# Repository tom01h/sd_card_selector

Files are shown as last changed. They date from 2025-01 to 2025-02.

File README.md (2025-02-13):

# ラズパイ5のマイクロSDカードをリモートで書き換えたり、リモートで電源ONにできるやつ

## できること
- マイクロSDカードの接続をラズパイとUSBカードリーダーで切り替えられる
    - 接続の切り替え部分は[これ](https://x.com/task_jp/status/1864548270422573205)の真似
- 電源ボタンを押したのと同じことができる
    - [この資料](https://www.raspberrypi.com/documentation/computers/raspberry-pi.html#add-your-own-power-button)の通りに制御する
- 電源の状態を知れる
    - マイクロSDに供給されている電源を監視
- PCとUSB-UART的なもの（正確にはUSB CDC ACM）で繋ぐ
    - CH552マイコンを使って制御している

## 使い方
こんな感じに組み立てます  
USB-UARTもあったほうが便利です  
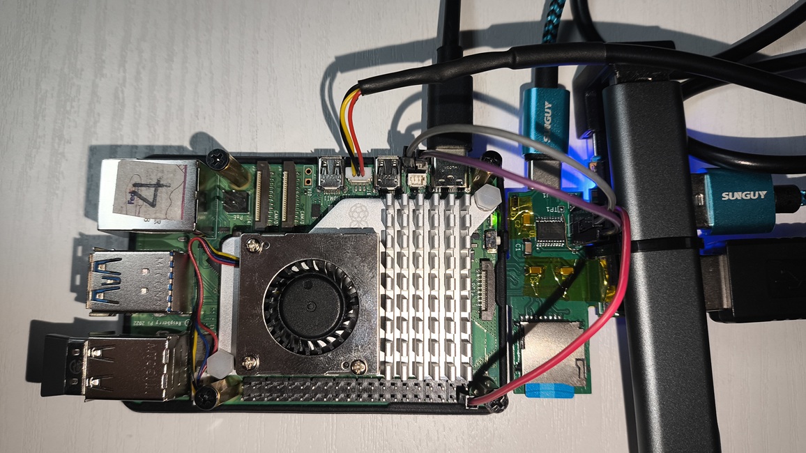
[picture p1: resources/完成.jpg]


ラズパイの電源を入れる前にUSBハブをPCに繋ぎます  
ターミナルの表示は以下  
この状態ではPCからuSDカードにアクセスできます  
```
Raspberry Pi Remote
USB Card Reader
USB> 
```

`rpi`を入力してuSDの接続をラズパイに切り替えます  
この状態ではPCからuSDカードにアクセスできません  
```
USB> rpi
Raspberry Pi
Pi Off>
```

ラスパイの電源を入れて、ターミナルでエンターを入力すると下のような表示になります  
```
Pi Off>
Undefined Command
Pi On>
```

ラスパイをシャットダウンして、ターミナルでエンターを入力すると下のような表示になります  
```
Pi On>
Undefined Command
Pi Off>
```

`pon`を入力してラズパイの電源をONにします  
ターミナルでエンターを入力すると下のような表示になります  
```
Pi Off> pon
Power ON
Pi Off>
Undefined Command
Pi On>
```

`Pi Off`の状態から`usb`コマンドを入力すると、PCからuSDカードにアクセス出来るようになります  
```
Pi Off> usb
USB Card Reader
USB>
```

`Pi On`状態で`shutdown`コマンド実行で、強制的にラズパイの電源をOFFにできます（OSのシャットダウンではありません）  
その後、PCからuSDカードにアクセス出来るようになります  

## 部品
- [USBハブ](https://ja.aliexpress.com/item/1005007046850790.html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)
- [USBカードリーダー](https://ja.aliexpress.com/item/1005007634731826.html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)
- [USBエクステンションアダプター](https://ja.aliexpress.com/item/1005007404846946.html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)
    - コの字型でUSB3.0のやつ
- 自作の基板
    - 設計データはKiCadディレクトリ以下
    - 基板の厚さは0.8mm

### 基板に乗せる部品
- [CH552](https://ja.aliexpress.com/item/1005004508033849.html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)
    - CH552T
- [tmux1574pwr](https://ja.aliexpress.com/item/1005007848132137.html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)
- [1N5819 SOD-123](https://ja.aliexpress.com/item/1005003194674618.html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)
- [XC6206P332MR](https://ja.aliexpress.com/item/1005002918096822.html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)
- [ボタン](https://ja.aliexpress.com/item/32756768334.html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)
    - 買ったやつはリンクなくなった・多分これと同じ
- 抵抗とか容量は1206サイズ（3.2mmx1.6mm）

## 基板の繋ぎ方
### 作成した基板の実装
こんな感じ  
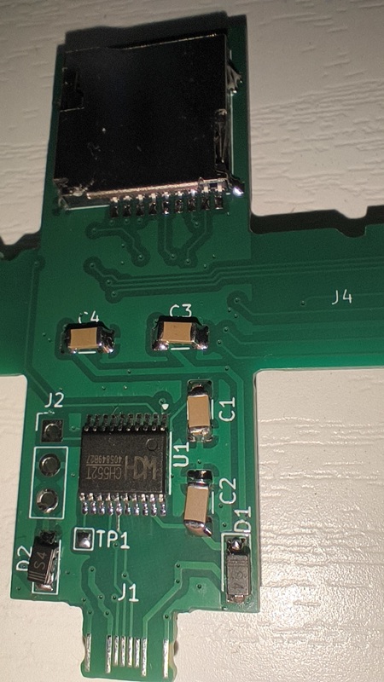
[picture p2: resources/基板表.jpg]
  
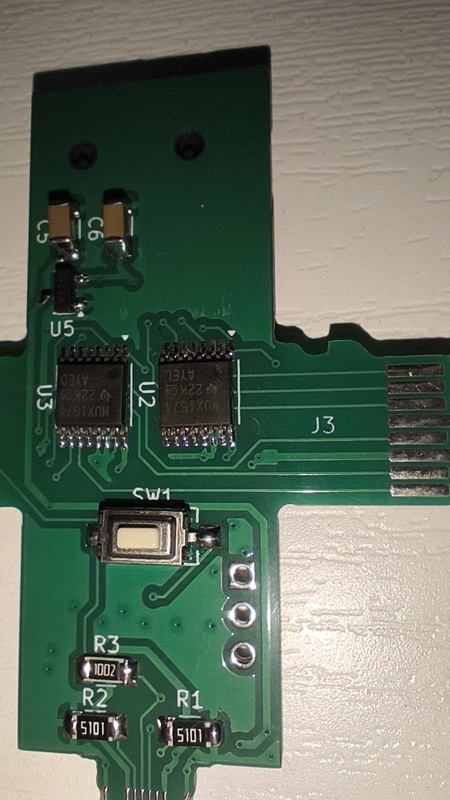
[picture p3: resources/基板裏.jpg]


uSDカードスロットのフットプリントはギリギリ使えるくらいにずれています

### SDカードリーダーの改造
カードリーダーの基板を取り出します  
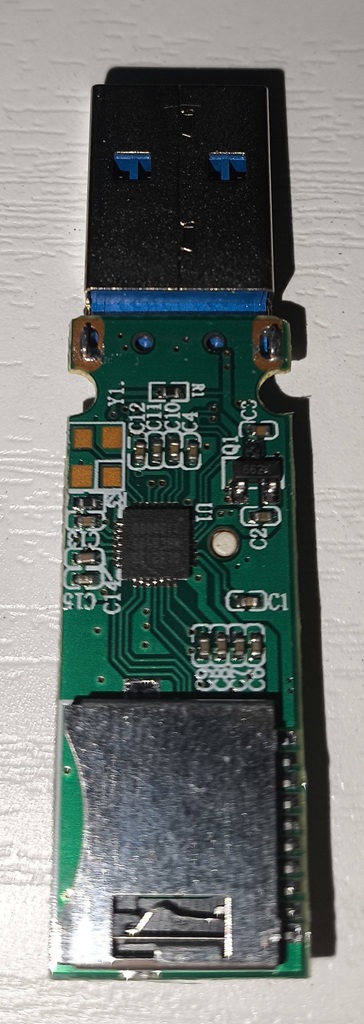
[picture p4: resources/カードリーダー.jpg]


uSDスロットのカードデテクトを壊します  
カードを入れてもdetectピンがグランドに落ちないようにします  
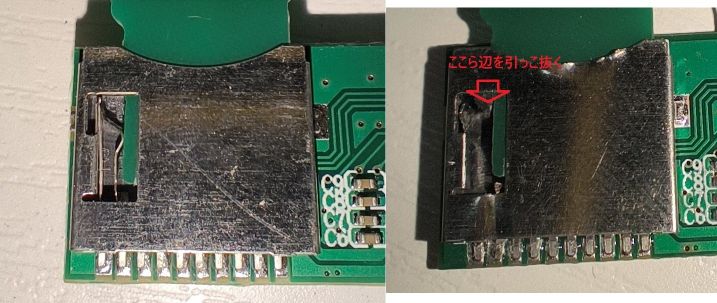
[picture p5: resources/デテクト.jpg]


カードリーダーのSDスロットを外します  
外したソケットのパターンのデテクトピンと作成した基板のTP1を繋ぎます  
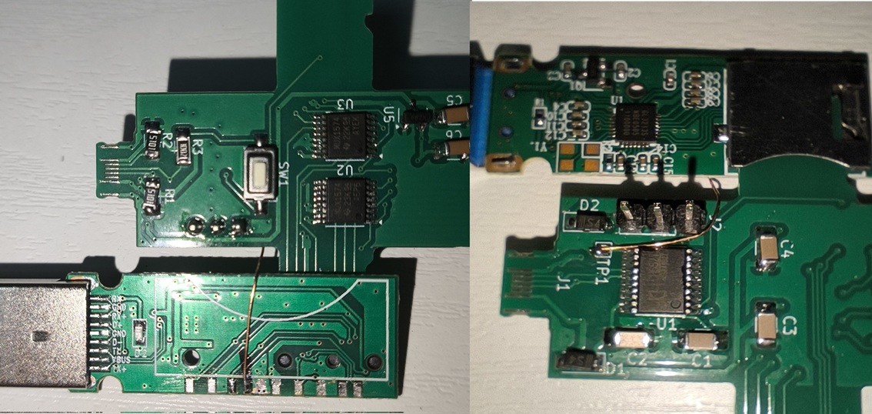
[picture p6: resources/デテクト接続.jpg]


### USBハブの接続
コの字型のアダプタも使ってこんな感じにつなぐ  
5㎜厚の両面テープを3段重ねで止めています  
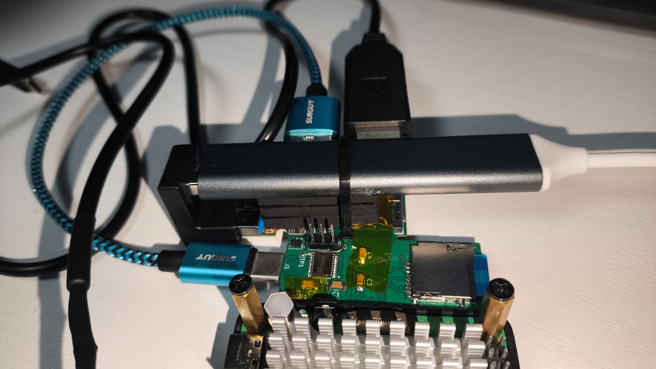
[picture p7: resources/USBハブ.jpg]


### ピンヘッダ(J2)の接続
- 1PINはPSWピンヘッダの1PIN
- 2PINはPSWピンヘッダの2PIN (GND)
- 3PINはラズパイピンヘッダの5V出力
    - 電源はUSBからもとっているので、この接続がなくても動きます

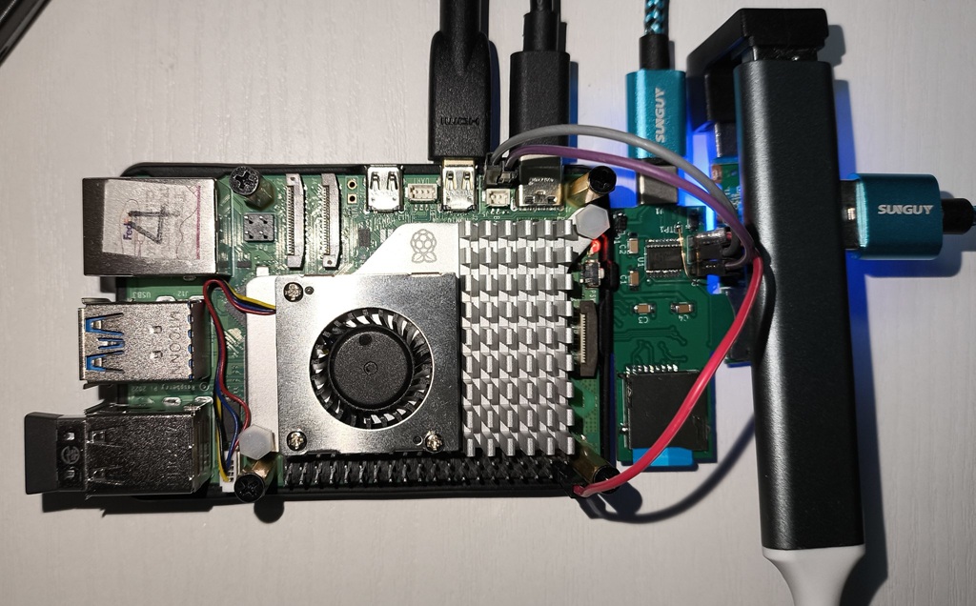
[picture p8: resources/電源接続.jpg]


## CH552のソフト
[ch55xduino](https://github.com/DeqingSun/ch55xduino)を使って、CH552にArduino IDEからプログラム(Arduino/SDSEL/SDSEL.ino)を書きみます  
プログラムの書き込みには[WCHISPTool](https://www.wch.cn/downloads/WCHISPTool_Setup_exe.html)が必要です

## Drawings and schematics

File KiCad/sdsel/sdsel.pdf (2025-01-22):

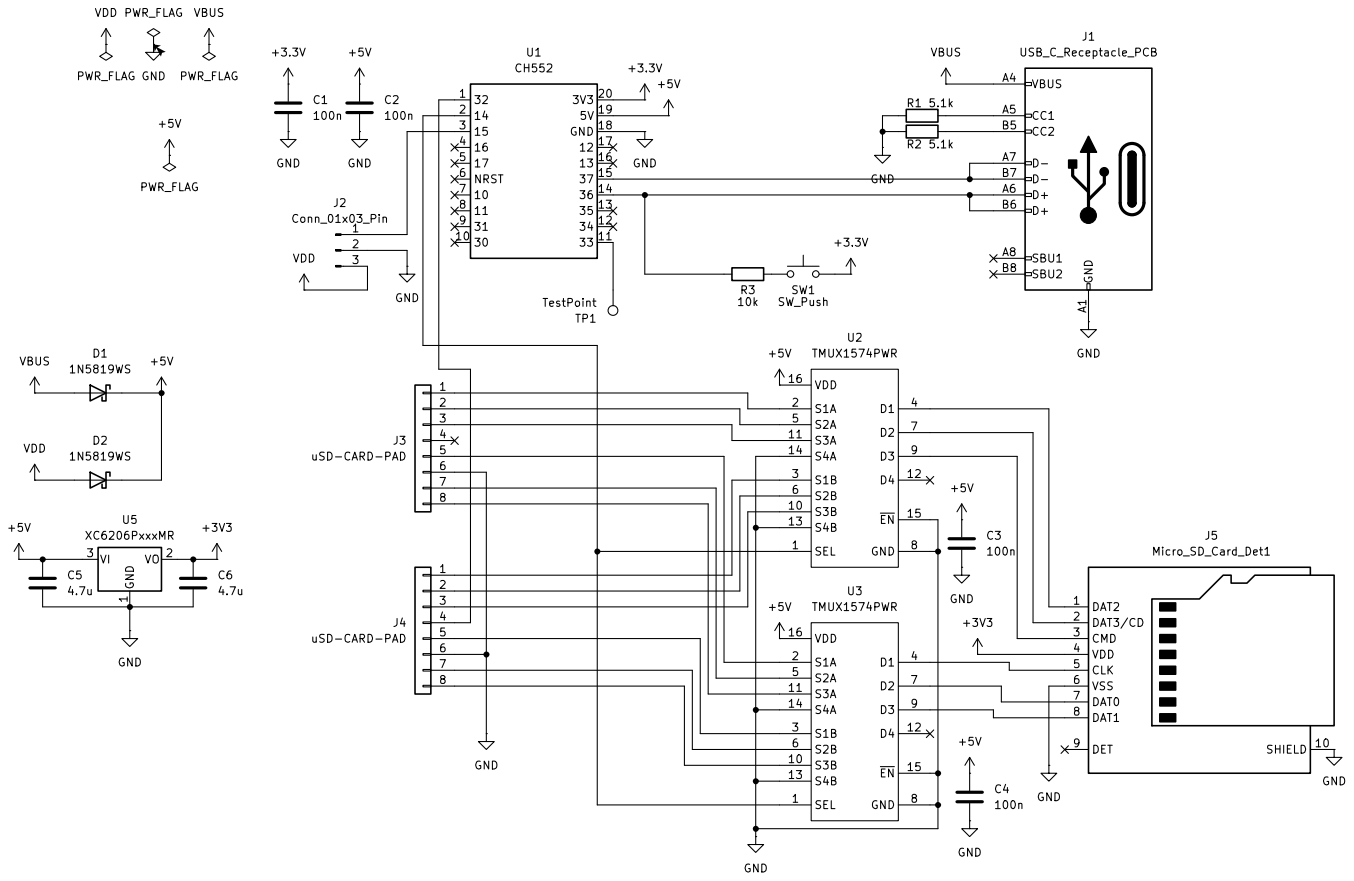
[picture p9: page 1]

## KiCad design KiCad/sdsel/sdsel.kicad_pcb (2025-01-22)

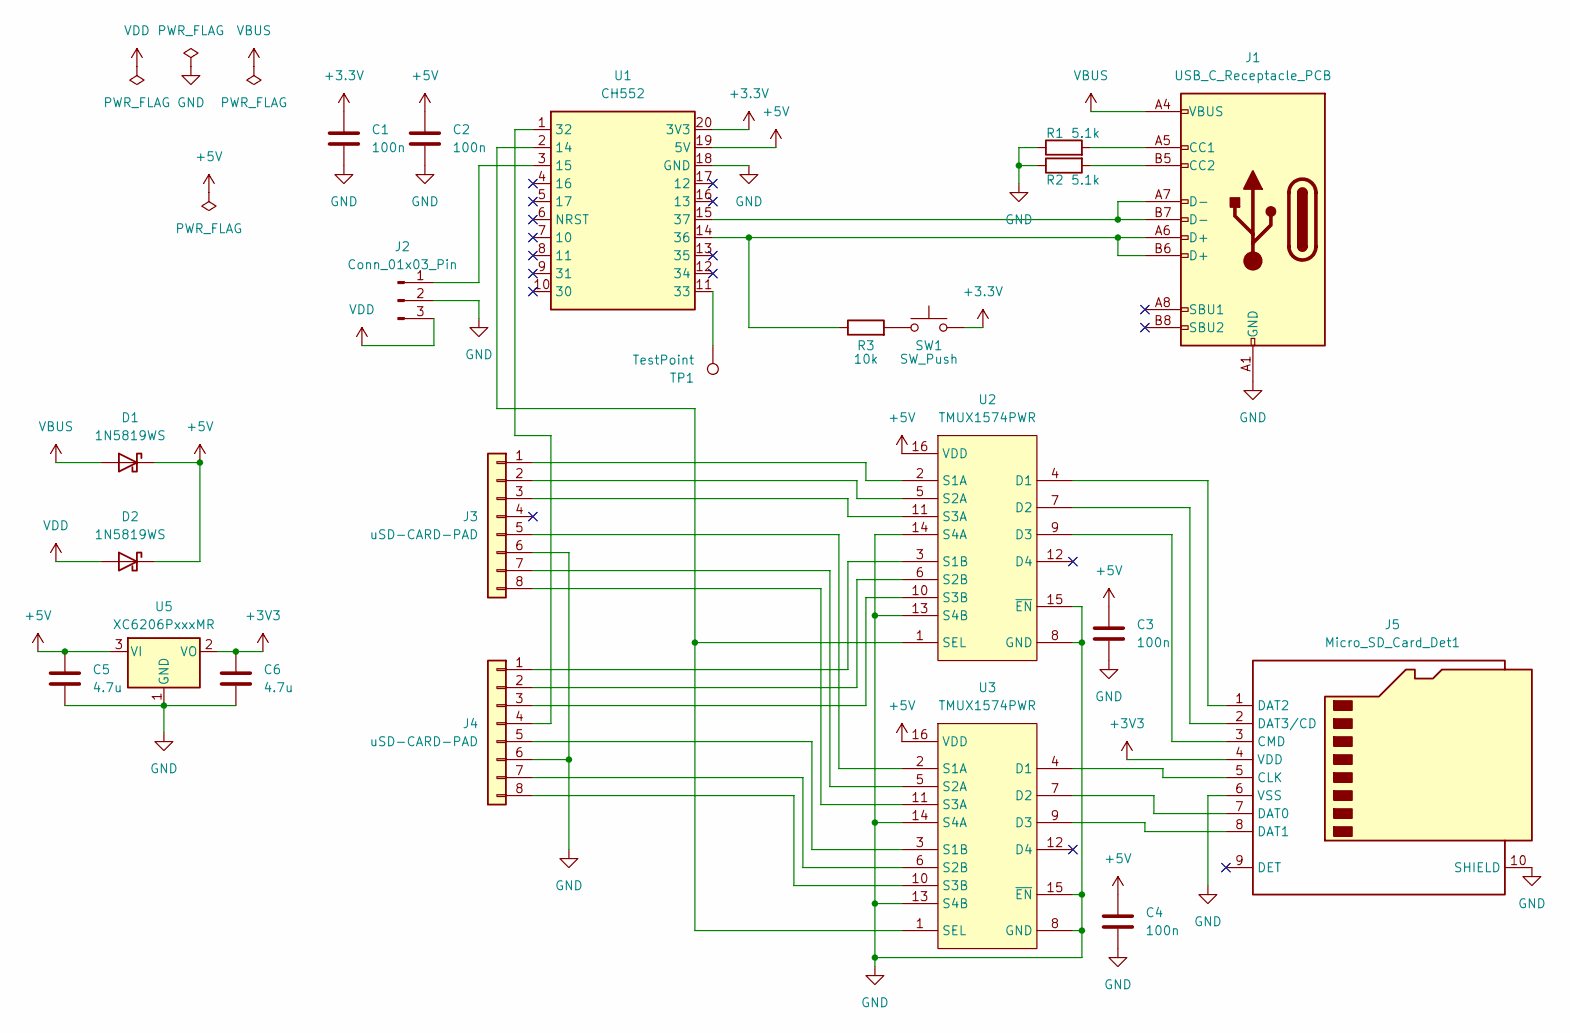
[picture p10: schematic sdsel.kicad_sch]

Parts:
C1, C2, C3, C4: 100n; C_1206_3216Metric_Pad1.33x1.80mm_HandSolder
C5, C6: 4.7u; C_1206_3216Metric_Pad1.33x1.80mm_HandSolder
D1, D2: 1N5819WS; Nexperia_CFP3_SOD-123W
J1: USB_C_Receptacle_PCB
J2: Conn_01x03_Pin; PinHeader_1x03_P2.54mm_Vertical
J3, J4: uSD-CARD-PAD; uSD-PAD
J5: Micro_SD_Card_Det1; microsd
R1, R2: 5.1k; R_1206_3216Metric_Pad1.30x1.75mm_HandSolder
R3: 10k; R_1206_3216Metric_Pad1.30x1.75mm_HandSolder
SW1: SW_Push; SW_SPST_CK_RS282G05A3
TP1: TestPoint; TestPoint_Pad_1.0x1.0mm
U1: CH552; TSSOP-20_4.4x6.5mm_P0.65mm
U2, U3: TMUX1574PWR; TSSOP-16_4.4x5mm_P0.65mm
U5: XC6206PxxxMR; SOT-23-3

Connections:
+3.3V: C1.1, SW1.2, U1.20 (3V3)
+3V3: C6.1, J5.4 (VDD), U5.2 (VO)
+5V: C2.1, C3.1, C4.1, C5.1, D1.1 (K), D2.1 (K), U1.19 (5V), U2.16 (VDD), U3.16 (VDD), U5.3 (VI)
GND: C1.2, C2.2, C3.2, C4.2, C5.2, C6.2, J1.A1 (GND), J1.A12 (GND), J1.B1 (GND), J1.B12 (GND), J2.2, J3.6, J4.6, J5.6 (VSS), J5.10 (SHIELD), R1.1, R2.1, U1.18 (GND), U2.8 (GND), U2.13 (S4B), U2.14 (S4A), U2.15 (~EN), U3.8 (GND), U3.13 (S4B), U3.14 (S4A), U3.15 (~EN), U5.1 (GND)
unnamed: J1.A5 (CC1), R1.2
unnamed: J1.B5 (CC2), R2.2
unnamed: J2.1, U1.3 (15)
unnamed: J3.1, U2.2 (S1A)
unnamed: J3.2, U2.5 (S2A)
unnamed: J3.3, U2.11 (S3A)
unnamed: J3.5, U3.2 (S1A)
unnamed: J3.7, U3.5 (S2A)
unnamed: J3.8, U3.11 (S3A)
unnamed: J4.1, U2.3 (S1B)
unnamed: J4.2, U2.6 (S2B)
unnamed: J4.3, U2.10 (S3B)
unnamed: J4.4, U1.1 (32)
unnamed: J4.5, U3.3 (S1B)
unnamed: J4.7, U3.6 (S2B)
unnamed: J4.8, U3.10 (S3B)
unnamed: J5.5 (CLK), U3.4 (D1)
unnamed: J5.3 (CMD), U2.9 (D3)
unnamed: J5.7 (DAT0), U3.7 (D2)
unnamed: J5.8 (DAT1), U3.9 (D3)
unnamed: J5.1 (DAT2), U2.4 (D1)
unnamed: J5.2 (DAT3/CD), U2.7 (D2)
unnamed: R3.2, SW1.1
unnamed: U1.2 (14), U2.1 (SEL), U3.1 (SEL)
unnamed: TP1.1, U1.11 (33)
unnamed: J1.A6 (D+), J1.B6 (D+), R3.1, U1.14 (36)
unnamed: J1.A7 (D-), J1.B7 (D-), U1.15 (37)
VBUS: D1.2 (A), J1.A4 (VBUS), J1.A9 (VBUS), J1.B4 (VBUS), J1.B9 (VBUS)
VDD: D2.2 (A), J2.3

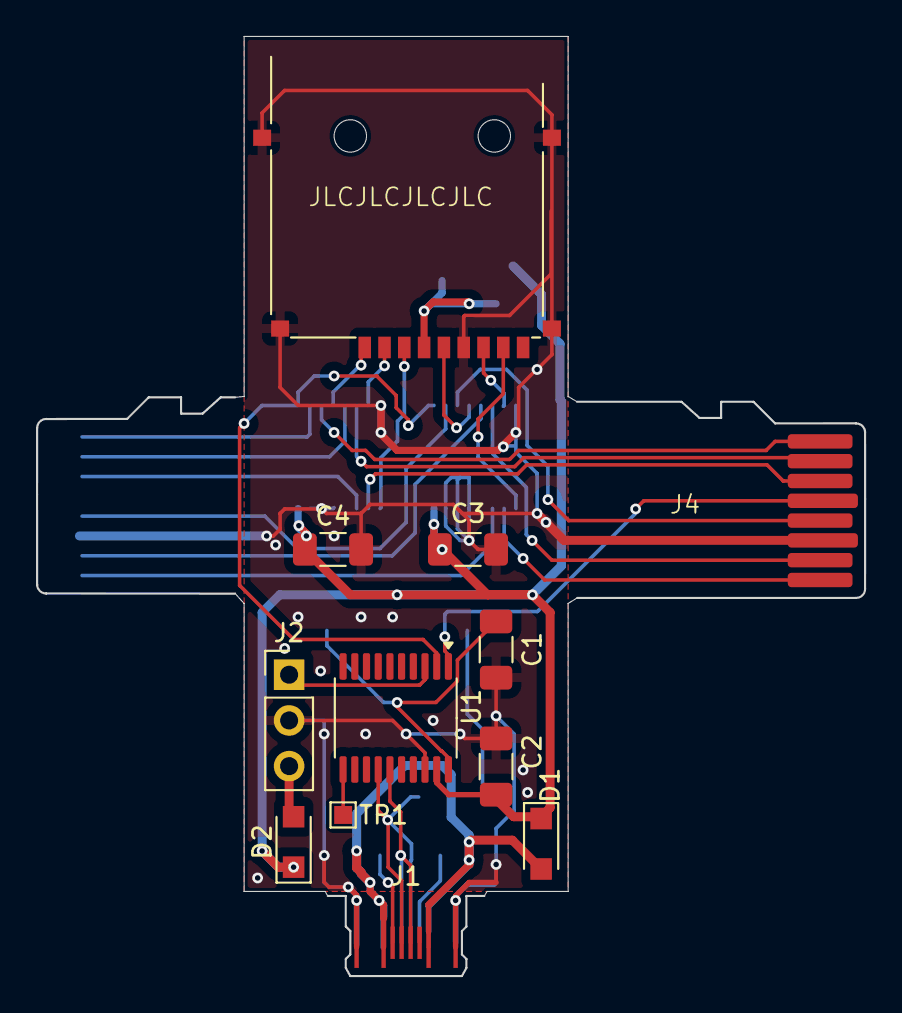
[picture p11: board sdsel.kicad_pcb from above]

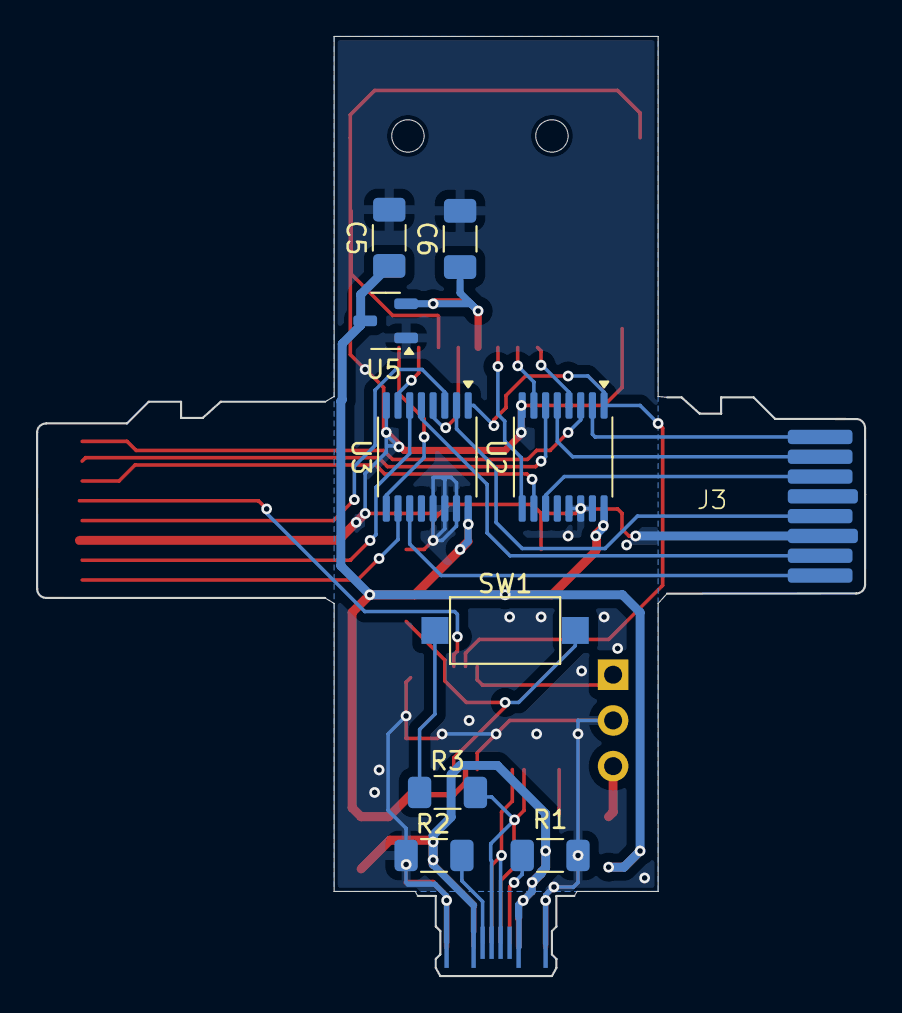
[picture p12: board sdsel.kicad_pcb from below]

Board: 2 copper layers, 46.0 x 52.2 mm, 22 parts (10 on the bottom side), 33 nets.

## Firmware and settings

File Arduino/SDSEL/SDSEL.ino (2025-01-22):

#define SELECT 14 // Card HIGH:PI / LOW:USB 
#define DETECT 33 // Card LOW:DETECT 
#define PSW 15 // PSW Switch 
#define PWRDET 32 // Power Detect

#include<ctype.h>

__xdata char recvStr[64];
uint8_t recvStrPtr = 0;
bool stringComplete = false;
uint16_t echoCounter = 0;

enum {S_USB=0, S_PI_OFF, S_PI_ON, S_INVALID};
uint8_t status=S_USB;
//uint8_t status=S_PI_OFF;

void prompt(){
  switch(status){
    case S_USB: USBSerial_print("USB> "); break;
    case S_PI_OFF: USBSerial_print("Pi Off> "); break;
    case S_PI_ON: USBSerial_print("Pi On> "); break;
    case S_INVALID: USBSerial_print("INVALID> "); break;
  }
  USBSerial_flush();
}

void setup() {
  // put your setup code here, to run once:
  pinMode(SELECT, OUTPUT);
  pinMode(DETECT, OUTPUT_OD);
  pinMode(PSW, OUTPUT_OD);
  pinMode(PWRDET, INPUT);

  digitalWrite(PSW, HIGH);
  
  digitalWrite(SELECT, LOW);
  delay(100);
  digitalWrite(DETECT, LOW);

  while (!USBSerial()) {
    ; // wait for serial port to connect. Needed for native USB port only
  }
  
  USBSerial_println("");
  USBSerial_println("Raspberry Pi Remote");
  USBSerial_println("USB Card Reader");
  if(digitalRead(PWRDET)==0){
    status=S_USB;
  }else{
    status=S_INVALID;
  }
  //if(digitalRead(PWRDET)==0){
  //  status=S_PI_OFF;
  //}else{
  //  status=S_PI_ON;
  //}
  prompt();
}

void loop() {
  // put your main code here, to run repeatedly:
  if (stringComplete) {
    if(digitalRead(PWRDET)==0){
      switch(status){
        case S_USB: status=S_USB; break;
        case S_PI_OFF: status=S_PI_OFF; break;
        case S_PI_ON: status=S_PI_OFF; break;
        case S_INVALID: status=S_USB; break;
      }
    }else{
      switch(status){
        case S_USB: status=S_INVALID; break;
        case S_PI_OFF: status=S_PI_ON; break;
        case S_PI_ON: status=S_PI_ON; break;
        case S_INVALID: status=S_INVALID; break;
      }
    }
    
    USBSerial_println("");
    if(strcmp(recvStr, "usb")==0){
      if(status==S_PI_OFF){
        status=S_USB;
        USBSerial_println("USB Card Reader");
        digitalWrite(SELECT, LOW);
        delay(100);
        digitalWrite(DETECT, LOW);
      }else{
        USBSerial_println("Invalid Command");
      }
    }else if(strcmp(recvStr, "rpi")==0){
      if(status==S_USB){
        status=S_PI_OFF;
        USBSerial_println("Raspberry Pi");
        digitalWrite(DETECT, HIGH);
        delay(100);
        digitalWrite(SELECT, HIGH);
      }else{
        USBSerial_println("Invalid Command");
      }
    }else if(strcmp(recvStr, "pon")==0){
      if(status==S_PI_OFF){
        //status=S_PI_ON;
        USBSerial_println("Power ON");
        digitalWrite(PSW, LOW);
        delay(300);
        digitalWrite(PSW, HIGH);
      }else{
        USBSerial_println("Invalid Command");
      }
    }else if(strcmp(recvStr, "shutdown")==0){
      if(status==S_PI_ON || status==S_INVALID){
        status=S_USB;
        USBSerial_println("Shutdown");
        digitalWrite(PSW, LOW);
        delay(6000);
        digitalWrite(PSW, HIGH);
        delay(100);
        digitalWrite(SELECT, LOW);
        delay(100);
        digitalWrite(DETECT, LOW);
      }else{
        USBSerial_println("Invalid Command");
      }
    }else if(strcmp(recvStr, "help")==0){
      USBSerial_println("rpi: Raspberry Pi");
      USBSerial_println("usb: USB Card Reader");
      USBSerial_println("pon: Power ON");
      USBSerial_println("shutdown: Shutdown");
    }else{
      USBSerial_println("Undefined Command");
    }

    prompt();

    stringComplete = false;
    recvStrPtr = 0;
  }

  if (USBSerial_available()) {
    char serialChar = USBSerial_read();
    if ((serialChar == '\n') || (serialChar == '\r') ) {
      recvStr[recvStrPtr] = '\0';
      stringComplete = true;
    } else {
      recvStr[recvStrPtr] = tolower(serialChar);
      recvStrPtr++;
      USBSerial_write(serialChar);
      if (recvStrPtr == 63) {
        recvStr[recvStrPtr] = '\0';
        stringComplete = true;
      }
    }
    USBSerial_flush();
  }
}

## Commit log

2025-01-23 基板の繋ぎ方
2025-02-13 README
    カードデテクトの破壊方法変更
